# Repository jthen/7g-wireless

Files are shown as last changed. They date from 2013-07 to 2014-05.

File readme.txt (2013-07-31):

I've added a few things since my last update.

The first is the ability to "play" a text string as keystrokes on the receiver. So, the keyboards sends the string "this is a message" to the receiver which is then translated into keystrokes. These keystrokes are then sent to the PC as if the user typed "this is a message".

I used this to build a menu system which at the moment is used to set the brightness of the LEDs and the output power of the transmitter. Pressing Func+Esc enters the menu and this is what it currently looks:

[code]
7G wireless
firmware build Jul 30 2013  13:38:18
battery voltage=2.83V
keyboard's been on for 0days 21hour 39min 10sec

what do you want to do?
F1 - change transmitter output power (current 0dBm)
F2 - change LED brightness (current 1)
Esc - exit menu
[/code]
Pressing F1 or F2 then opens a sub-menu which allows changing these values.

The menu shows the current battery voltage. This needs a little tweaking to be more accurate, but it serves it's purpose at the moment. In the next PCB revision, I want to improve the circuit which measures the voltage. I have to dig into the AVR datasheets and look for some examples.

The firmware also has a clock (watch) which starts when the keyboard receives power. That's the "keyboard's been on for..." part of the menu. This clock is used in the sleep system (see below), but can be used as a real clock too.

There is also a LED "driver" thing which allows sequences to be replayed. So, for instance, I can play an LED sequence where 1 LED is on for a while, then 2, then all three. The driver also allows gradual transitions from bright do dim and back, but this still needs some testing, I think there are bugs in it. This can be used for all sorts of indicators.

The bad news: transmitter range sucks! On highest transmitter output power (0dBm) I get a range of 6-8 meters, and on the lowest I get 1-2 meters tops. I've used these modules for other projects, and I've confirmed a range of at least 60 meters. The chip should also be able to send a signal through at least one wall, which is not the case now. This, of course, means there is something wrong. I don't know what causes these, but I'm guessing either the keyboard PCB or my controller PCB are somehow shielding the transmitter. Tests are needed...

I don't do any frequency hopping. The channel is hard-coded at the moment. The transmitter will to re-send the package for for a number of times, or until it gets an acknowledge from the dongle.

The controller does not have any reverse voltage protection. So, reversing the batteries will probably fry the entire circuit. I will have to add this in the next controller revision.

The firmware doesn't do any encryption of the data it sends. This means that it's not too hard to build a circuit that can "listen" and log keystrokes. This can be fixed, of course, but it's not very high on my priority list. I'm not very paranoid...

The firmware puts the keyboard into sleep for a variable duration of time which depends on the time since the last change of the state of the keys. The idea is that while the user is typing, this sleep time will stay relatively short (say, 4ms) and if the user is not typing this interval will gradually increase to a max value (at the moment 71ms). Then, as soon as the user starts typing again, the sleep duration will jump back to the minimal value. Currently the implementaion of this is very crude, and needs more work. I plan to make this configurable so that the user can select if he wants to save power with longer sleeps, or have a more responsive keyboard and drain the batteries quicker. I also thought about making a "deep sleep" mode which puts the keyboard in a state where it will sleep for longer durations (say, 500ms) between matrix scans and wait for a specific key combination to get out of this deep sleep. The idea here is that you want to put the keyboard in deep sleep if you want to transport it, or if you want to lock it. The keyboard could also go into deep sleep if no keys have been pressed for a long time (30 minutes or so) to preserve power.

Because of this sleep system I decided I will not do any debouncing. What's the point of debouncing if I'm already scanning the keyboard matrix every 4ms or longer? Any comments on this?

The source code and the Eagle CAD schematics of the controller PCB are on:

https://code.google.com/p/7g-wireless/

So, that's it for now.

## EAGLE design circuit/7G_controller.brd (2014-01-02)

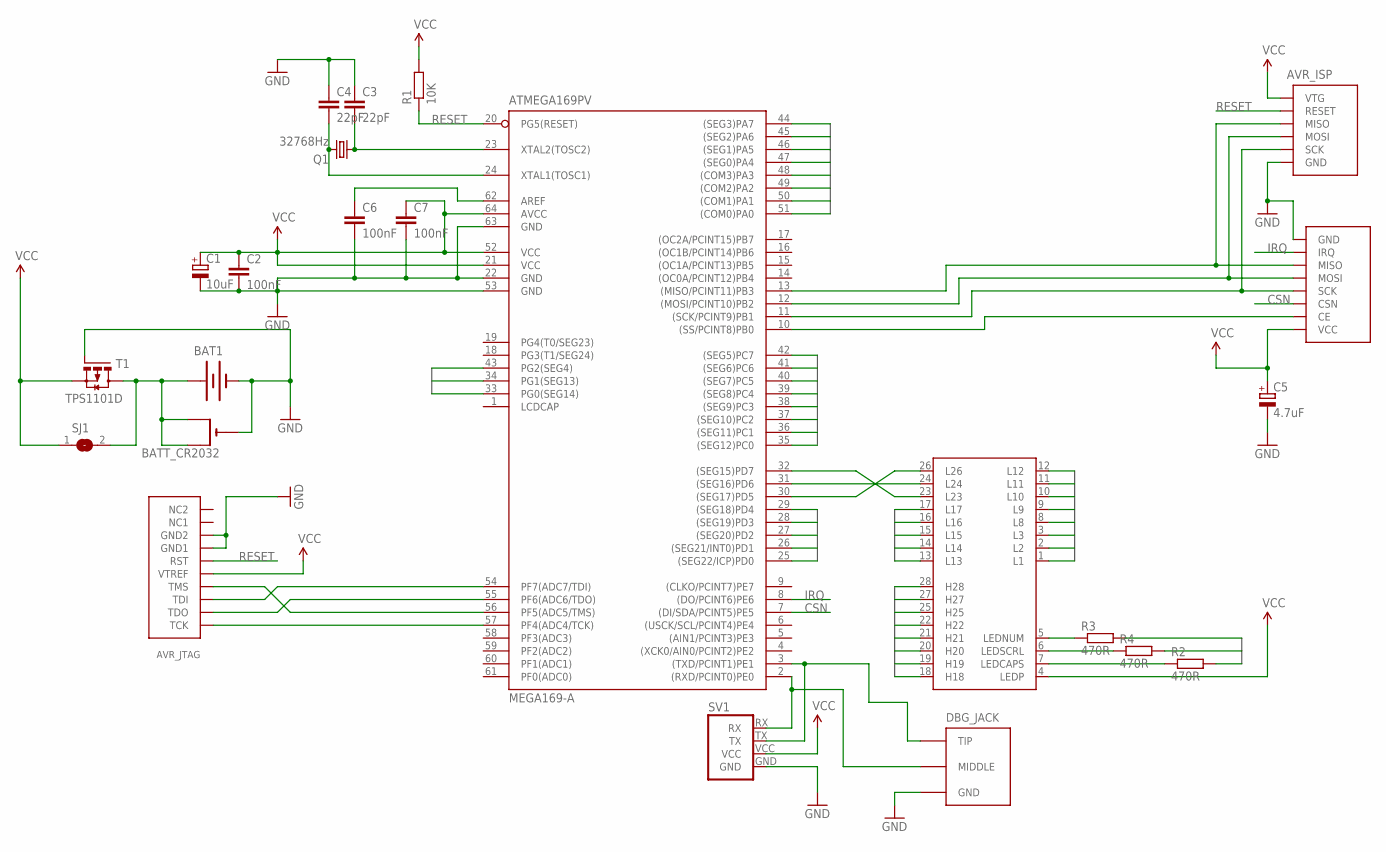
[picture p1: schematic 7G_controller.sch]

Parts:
ATMEGA169PV: MEGA169-A; TQFP64
AVR_ISP: AVR-ISP-6SMALL_FP; AVR-ISP-6-SMALL-FP
AVR_JTAG: AVR-JTAG
BAT1: BATTERYPLAIN; BATTERY
BATT_CR2032: CR2032SMT; CR2032-SMD
C1: 10uF; SMC_B
C2, C6, C7: 100nF; C0805
C3, C4: 22pF; C0805
C5: 4.7uF; SMC_B
DBG_JACK: JACK_FEMALE_3.5MMCHEAP; JACK_CHEAP
MTRX_CONN: SS7G_CONNSMD; SS7G_CONN_SMD
NRF24L01: NRF24L01_MOD_NINE_EAGLESGENERIC; NRF24L01_MOD_GENERIC
Q1: 32768Hz; NSK_QUARTZ_CLOCK
R1: 10K; R0805
R2, R3, R4: 470R; R0805
SJ1: SJ
SV1: UART_PORT
T1: TPS1101D; SO8

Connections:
AREF: ATMEGA169PV.62 (AREF), C6.1
CAPS: ATMEGA169PV.43 (PG2(SEG4)), R2.2
CE: ATMEGA169PV.10 ((SS/PCINT8)PB0), NRF24L01.CE
CSN: ATMEGA169PV.7 ((DI/SDA/PCINT5)PE5), NRF24L01.CSN
GND: ATMEGA169PV.22 (GND), ATMEGA169PV.53 (GND), ATMEGA169PV.63 (GND), AVR_ISP.GND, AVR_JTAG.P$2 (GND1), AVR_JTAG.P$10 (GND2), BAT1.-, BATT_CR2032.-, C1.-, C2.2, C3.1, C4.1, C5.-, C6.2, C7.2, DBG_JACK.1 (GND), NRF24L01.GND, SV1.GND, T1.4 (G)
H18: ATMEGA169PV.42 ((SEG5)PC7), MTRX_CONN.18 (H18)
H19: ATMEGA169PV.41 ((SEG6)PC6), MTRX_CONN.19 (H19)
H20: ATMEGA169PV.40 ((SEG7)PC5), MTRX_CONN.20 (H20)
H21: ATMEGA169PV.38 ((SEG9)PC3), MTRX_CONN.21 (H21)
H22: ATMEGA169PV.36 ((SEG11)PC1), MTRX_CONN.22 (H22)
H25: ATMEGA169PV.35 ((SEG12)PC0), MTRX_CONN.25 (H25)
H27: ATMEGA169PV.37 ((SEG10)PC2), MTRX_CONN.27 (H27)
H28: ATMEGA169PV.39 ((SEG8)PC4), MTRX_CONN.28 (H28)
IRQ: ATMEGA169PV.8 ((DO/PCINT6)PE6), NRF24L01.IRQ
L1: ATMEGA169PV.50 ((COM1)PA1), MTRX_CONN.1 (L1)
L2: ATMEGA169PV.48 ((COM3)PA3), MTRX_CONN.2 (L2)
L3: ATMEGA169PV.46 ((SEG1)PA5), MTRX_CONN.3 (L3)
L8: ATMEGA169PV.45 ((SEG2)PA6), MTRX_CONN.8 (L8)
L9: ATMEGA169PV.44 ((SEG3)PA7), MTRX_CONN.9 (L9)
L10: ATMEGA169PV.25 ((SEG22/ICP)PD0), MTRX_CONN.10 (L10)
L11: ATMEGA169PV.26 ((SEG21/INT0)PD1), MTRX_CONN.11 (L11)
L12: ATMEGA169PV.27 ((SEG20)PD2), MTRX_CONN.12 (L12)
L13: ATMEGA169PV.28 ((SEG19)PD3), MTRX_CONN.13 (L13)
L14: ATMEGA169PV.29 ((SEG18)PD4), MTRX_CONN.14 (L14)
L15: ATMEGA169PV.51 ((COM0)PA0), MTRX_CONN.15 (L15)
L16: ATMEGA169PV.49 ((COM2)PA2), MTRX_CONN.16 (L16)
L17: ATMEGA169PV.47 ((SEG0)PA4), MTRX_CONN.17 (L17)
LEDCAPS: MTRX_CONN.7 (LEDCAPS), R2.1
LEDNUM: MTRX_CONN.6 (LEDSCRL), R4.1
LEDSCRL: MTRX_CONN.5 (LEDNUM), R3.1
MISO: ATMEGA169PV.13 ((MISO/PCINT11)PB3), AVR_ISP.MISO, NRF24L01.MISO
MOSI: ATMEGA169PV.12 ((MOSI/PCINT10)PB2), AVR_ISP.MOSI, NRF24L01.MOSI
unnamed: ATMEGA169PV.32 ((SEG15)PD7), MTRX_CONN.23 (L23)
unnamed: BAT1.+, BATT_CR2032.+$1 (+), BATT_CR2032.+$2 (+1), SJ1.2, T1.5 (D), T1.6 (D), T1.7 (D), T1.8 (D)
unnamed: ATMEGA169PV.23 (XTAL2(TOSC2)), C3.2, Q1.1
unnamed: ATMEGA169PV.24 (XTAL1(TOSC1)), C4.2, Q1.4 (2)
unnamed: ATMEGA169PV.30 ((SEG17)PD5), MTRX_CONN.26 (L26)
unnamed: ATMEGA169PV.31 ((SEG16)PD6), MTRX_CONN.24 (L24)
unnamed: ATMEGA169PV.2 ((RXD/PCINT0)PE0), DBG_JACK.4 (MIDDLE), SV1.RX
unnamed: ATMEGA169PV.3 ((TXD/PCINT1)PE1), DBG_JACK.2 (TIP), DBG_JACK.3 (TIP), SV1.TX
NUML: ATMEGA169PV.33 (PG0(SEG14)), R3.2
RESET: ATMEGA169PV.20 (PG5(RESET)), AVR_ISP.RESET, AVR_JTAG.P$6 (RST), R1.1
SCK: ATMEGA169PV.11 ((SCK/PCINT9)PB1), AVR_ISP.SCK, NRF24L01.SCK
SCRL: ATMEGA169PV.34 (PG1(SEG13)), R4.2
TCK: ATMEGA169PV.57 (PF4(ADC4/TCK)), AVR_JTAG.P$1 (TCK)
TDI: ATMEGA169PV.54 (PF7(ADC7/TDI)), AVR_JTAG.P$9 (TDI)
TDO: ATMEGA169PV.55 (PF6(ADC6/TDO)), AVR_JTAG.P$3 (TDO)
TMS: ATMEGA169PV.56 (PF5(ADC5/TMS)), AVR_JTAG.P$5 (TMS)
VCC: ATMEGA169PV.21 (VCC), ATMEGA169PV.52 (VCC), ATMEGA169PV.64 (AVCC), AVR_ISP.VCC (VTG), AVR_JTAG.P$4 (VTREF), C1.+, C2.1, C5.+, C7.1, MTRX_CONN.4 (LEDP), NRF24L01.+3.3V (VCC), R1.2, SJ1.1, SV1.VCC, T1.1 (S), T1.2 (S), T1.3 (S)

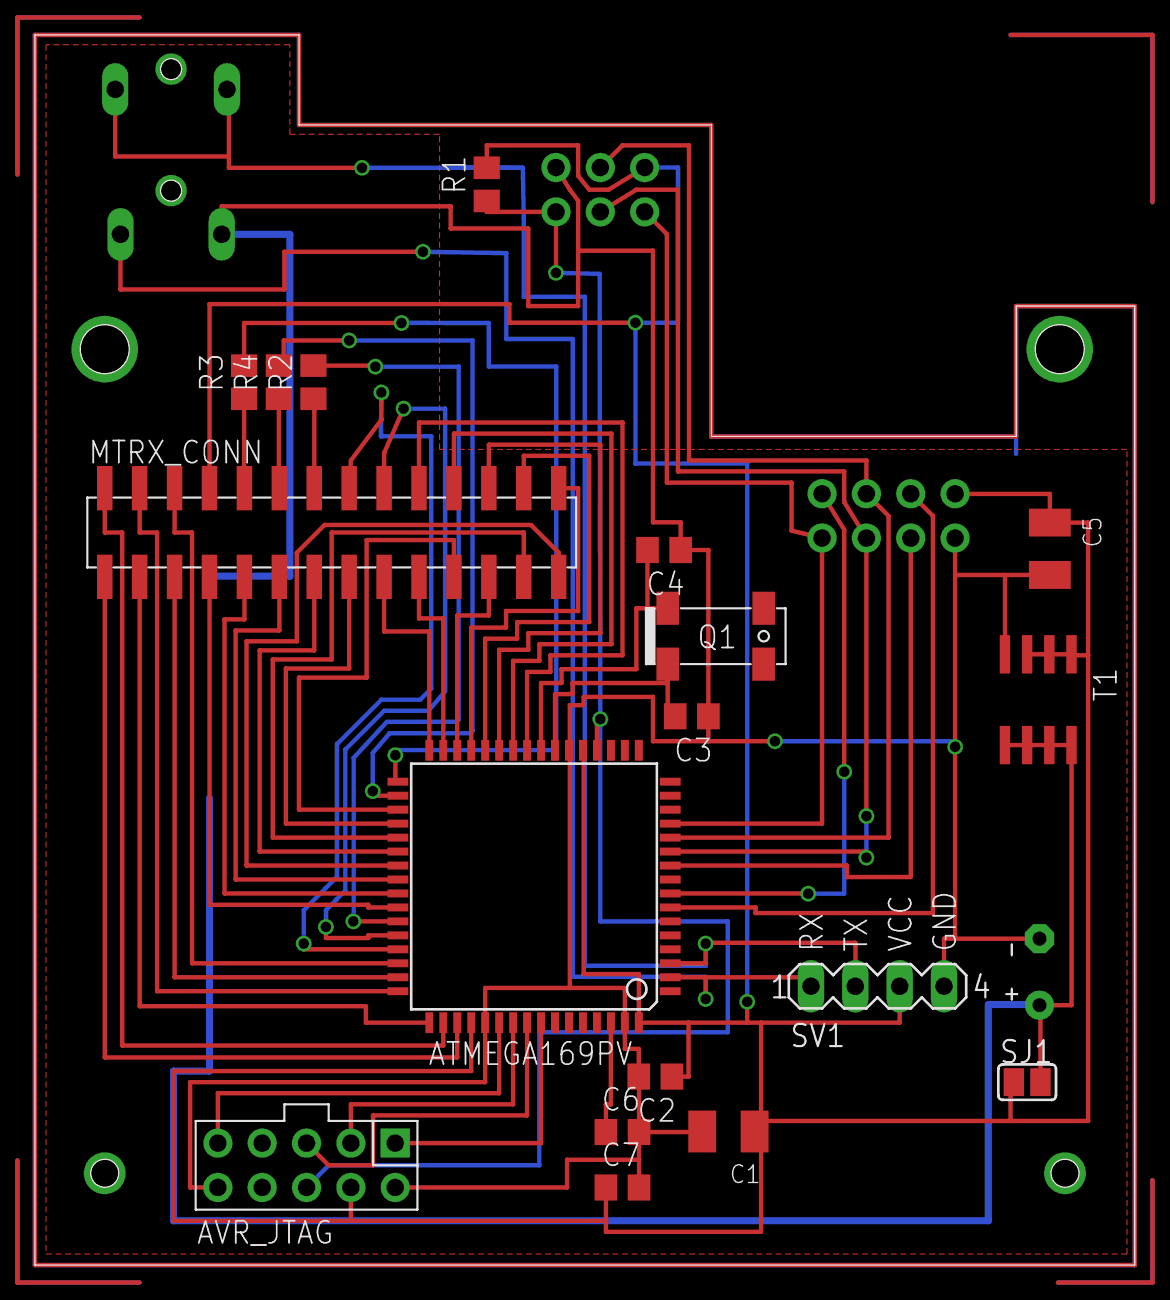
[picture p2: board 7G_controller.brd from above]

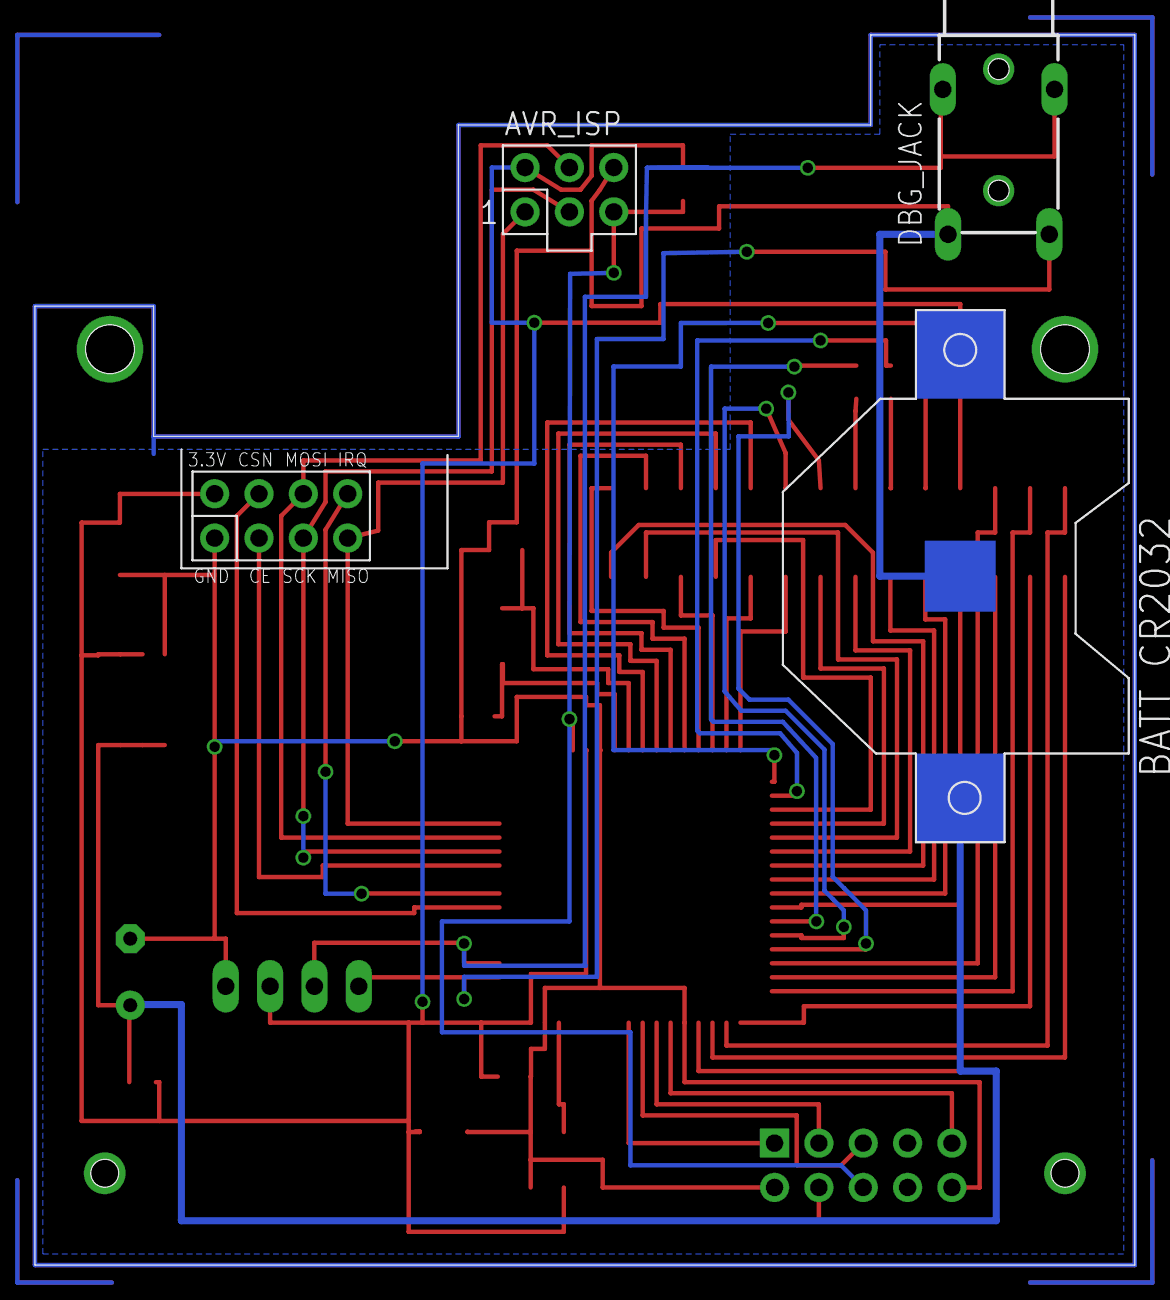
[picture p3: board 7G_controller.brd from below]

Board: 2 copper layers, 63.0 x 70.5 mm, 23 parts (4 on the bottom side), 49 nets.

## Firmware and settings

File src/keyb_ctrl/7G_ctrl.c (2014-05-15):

#include <stdint.h>
#include <stdbool.h>
#include <stdio.h>
#include <stdlib.h>
#include <string.h>

#include <avr/io.h>
#include <avr/pgmspace.h>
#include <avr/power.h>
#include <avr/interrupt.h>
#include <util/delay.h>

#include "hw_setup.h"
#include "avrdbg.h"
#include "avrutils.h"
#include "matrix.h"
#include "led.h"
#include "nRF24L.h"
#include "rf_protocol.h"
#include "rf_ctrl.h"
#include "keycode.h"
#include "sleeping.h"
#include "ctrl_settings.h"

// returns false if we should enter the menu, true if we should lock the keyboard
bool process_normal(void)
{
	bool waiting_for_all_keys_up = false;
	bool are_all_keys_up;
	bool ret_val = false;

	do {
		wait_for_matrix_change();

		// make a key state report
		rf_msg_key_state_report_t report;
		report.msg_type = MT_KEY_STATE;
		report.modifiers = 0;
		report.consumer = 0;

		uint8_t num_keys = 0;

		are_all_keys_up = true;
		
		if (is_pressed_keycode(KC_FN0))
		{
			are_all_keys_up = false;
			
			// set the bits of the consumer byte (media keys)
			if (is_pressed_keycode(KC_F1))		report.consumer |= _BV(FN_MUTE_BIT);
			if (is_pressed_keycode(KC_F2))		report.consumer |= _BV(FN_VOL_DOWN_BIT);
			if (is_pressed_keycode(KC_F3))		report.consumer |= _BV(FN_VOL_UP_BIT);
			if (is_pressed_keycode(KC_F4))		report.consumer |= _BV(FN_PLAY_PAUSE_BIT);
			if (is_pressed_keycode(KC_F5))		report.consumer |= _BV(FN_PREV_TRACK_BIT);
			if (is_pressed_keycode(KC_F6))		report.consumer |= _BV(FN_NEXT_TRACK_BIT);

			// if only Func and Esc are pressed
			if (get_num_keys_pressed() == 2)
			{
				if (is_pressed_keycode(KC_ESC))
				{
					waiting_for_all_keys_up = true;
				} else if (is_pressed_keycode(KC_L)) {
					waiting_for_all_keys_up = true;
					ret_val = true;
				} else if (is_pressed_keycode(KC_KP_MINUS)) {

					uint8_t curr_power = get_nrf_output_power();

					if (curr_power == vRF_PWR_0DBM)
						set_nrf_output_power(vRF_PWR_M6DBM);
					else if (curr_power == vRF_PWR_M6DBM)
						set_nrf_output_power(vRF_PWR_M12DBM);
					else if (curr_power == vRF_PWR_M12DBM)
						set_nrf_output_power(vRF_PWR_M18DBM);

				} else if (is_pressed_keycode(KC_KP_PLUS)) {

					uint8_t curr_power = get_nrf_output_power();

					if (curr_power == vRF_PWR_M18DBM)
						set_nrf_output_power(vRF_PWR_M12DBM);
					else if (curr_power == vRF_PWR_M12DBM)
						set_nrf_output_power(vRF_PWR_M6DBM);
					else if (curr_power == vRF_PWR_M6DBM)
						set_nrf_output_power(vRF_PWR_0DBM);
				}
			}

		} else {

			uint8_t row, col;
			for (row = 0; row < NUM_ROWS; ++row)
			{
				for (col = 0; col < NUM_COLS; ++col)
				{
					if (is_pressed_matrix(row, col))
					{
						are_all_keys_up = false;
						
						uint8_t keycode = get_keycode(row, col);
						
						if (IS_MOD(keycode))
							report.modifiers |= _BV(keycode - KC_LCTRL);
						else if (num_keys < MAX_KEYS)
							report.keys[num_keys++] = keycode;
					}
				}
			}
		}

		// send the report and wait for ACK
		if (!rf_ctrl_send_message(&report, num_keys + 3))
			return true;

		// flush the ACK payloads
		rf_ctrl_process_ack_payloads(NULL, NULL);
		
	} while (!waiting_for_all_keys_up  ||  are_all_keys_up);
	
	return ret_val;
}

bool send_text(const char* msg, bool is_flash, bool wait_for_finish)
{
#ifdef DBGPRINT
	// This needs an explanation: I am using the AVR Dragon to flash the keyboard firmware
	// and it looks like the dragon has a strong pullup on the MISO line. This pullup is
	// stronger than the nRF24L01+ MISO output driver, so if the programming ISP cable is plugged in
	// it keeps MISO high all the time, and I can't read anything from the nRF24L01+ and the send_text()
	// function will never return.
	//
	// So, instead of plugging the ISP cable in and out all the time while testing firmware updates,
	// we just output the text to UART and return
	if (is_flash)
		dprint_P(msg);
	else
		dprint(msg);
	_delay_ms(1);
	return true;
#endif

	// this message id is used to avoid presenting the same package to the dongle in case dongle
	// received the message, but the keyboard did not receive the ACK
	static uint8_t msg_id = 1;
	
	rf_msg_text_t txt_msg;
	txt_msg.msg_type = MT_TEXT;

	// send the message in chunks of MAX_TEXT_LEN
	uint16_t msglen = is_flash ? strlen_P(msg) : strlen(msg);
	uint8_t chunklen, msg_bytes_free;
	while (msglen)
	{
		// flush the ACK payload
		rf_ctrl_process_ack_payloads(&msg_bytes_free, NULL);
	
		// copy a chunk of the message
		chunklen = msglen > MAX_TEXT_LEN ? MAX_TEXT_LEN : msglen;
		if (is_flash)
			memcpy_P(txt_msg.text, msg, chunklen);
		else
			memcpy(txt_msg.text, msg, chunklen);

		msglen -= chunklen;
		msg += chunklen;

		// query the free space of the buffer on the dongle to see if
		// it is large enough to store the next chunk

		for (;;)
		{
			// send an empty text message; this causes the dongle to respond with ACK payload
			// that contains the number of bytes available in the dongle's text buffer
			if (!rf_ctrl_send_message(&txt_msg, 2))		// 1 byte for the message type ID, 1 for the msg_id
				return false;
			
			rf_ctrl_process_ack_payloads(&msg_bytes_free, NULL);
			
			// enough space in the dongle buffer?
			if (msg_bytes_free > chunklen + 1)
				break;
				
			sleep_ticks(40);		// doze off a little; roughly 10ms
		}
		
		// set the message id and send it on it's way
		msg_id = msg_id == 0xff ? 1 : msg_id + 1;
		txt_msg.msg_id = msg_id;
		if (!rf_ctrl_send_message(&txt_msg, chunklen + 2))
			return false;
	}

	// flush the ACK payload(s)
	rf_ctrl_process_ack_payloads(NULL, NULL);

	// wait for the buffer on the dongle to become empty
	// this will ensure that all the keystrokes are sent to the host and that subsequent
	// keystrokes we're sending won't mess up the text we want output at the host
	if (wait_for_finish)
	{
		uint8_t msg_bytes_capacity = 0;
		do {
			if (!rf_ctrl_send_message(&txt_msg, 2))
				return false;

			rf_ctrl_process_ack_payloads(&msg_bytes_free, &msg_bytes_capacity);
		} while (msg_bytes_free == 0  ||  msg_bytes_free != msg_bytes_capacity);
	}
	
	return true;
}

// defining this makes the ADC use the two least significant bits, but adds 24 bytes to the binary
#define PREC_BATT_VOLTAGE

// returns the battery voltage in 10mV units
// for instance: get_battery_voltage() returning 278 equals a voltage of 2.78V
uint16_t get_battery_voltage(void)
{
	power_adc_enable();
	
	ADMUX = _B0(REFS1) | _B1(REFS0)	// AVCC with external capacitor at AREF pin
#ifndef PREC_BATT_VOLTAGE	
			| _BV(ADLAR)			// left adjust ADC - drops the two LSBs
#endif
			| 0b11110;				// measure 1.1v internal reference

	ADCSRA = _BV(ADEN)					// enable ADC
			| _BV(ADPS2) | _BV(ADPS1) | _BV(ADPS0)	// prescaler 128
			| _BV(ADSC);				// start conversion
	
	// wait for the conversion to finish
	loop_until_bit_is_set(ADCSRA, ADIF);

	// remember the result
#ifdef PREC_BATT_VOLTAGE
	uint16_t adc_result = ADC;
#else	
	uint8_t adc_result = ADCH;
#endif
	
	// clear the ADIF bit by writing one
	SetBit(ADCSRA, ADIF);
	
	ADCSRA = 0;				// disable ADC
	
	power_adc_disable();	// ADC power off
	
#ifdef PREC_BATT_VOLTAGE
	return 112640 / adc_result;
#else
	return 28050 / adc_result;
#endif
}

// makes a battery voltage string in the 2.34V format
// the buff buffer has to be at least 6 bytes long
void get_battery_voltage_str(char* buff)
{
	uint16_t voltage = get_battery_voltage();
	buff[0] = '0' + voltage / 100;
	buff[1] = '.';
	buff[2] = '0' + (voltage / 10) % 10;
	buff[3] = '0' + voltage % 10;
	buff[4] = 'V';
	buff[5] = '\0';
}

// returns the keycode of the first key pressed and relased
uint8_t get_key_input(void)
{
	uint8_t keycode_pressed = KC_NO;
	
	wait_for_all_keys_up();
	wait_for_key_down();

	// scan for the key pressed
	uint8_t row, col;
	for (row = 0; row < NUM_ROWS; ++row)
	{
		for (col = 0; col < NUM_COLS; ++col)
		{
			if (is_pressed_matrix(row, col))
				keycode_pressed = get_keycode(row, col);
		}
	}
	
	wait_for_all_keys_up();
	
	return keycode_pressed;
}

bool process_menu(void)
{
	start_led_sequence(led_seq_menu_begin);
	
	// print the main menu
	uint8_t keycode;
	char* pEnd;
	const uint8_t BUFF_SIZE = 64;
	char string_buff[BUFF_SIZE];
	for (;;)
	{
		// welcome & version
		if (!send_text(PSTR("\x01"	// translates to Ctrl-A on the dongle
							"7G wireless\n"
							"firmware build " __DATE__ "  " __TIME__ "\n"
							"battery voltage: "), true, false))
			return true;
			
		get_battery_voltage_str(string_buff);
		if (!send_text(string_buff, false, false))		return true;

		// RF stats
		if (!send_text(PSTR("\nRF packet stats (total/retransmit/lost): "), true, false))		return true;
		
		ultoa(rf_packets_total, string_buff, 10);
		pEnd = strchr(string_buff, '\0');
		*pEnd++ = '/';
		
		ultoa(arc_total, pEnd, 10);
		pEnd = strchr(string_buff, '\0');
		*pEnd++ = '/';

		ultoa(plos_total, pEnd, 10);
		if (!send_text(string_buff, false, false))		return true;
		
		// output the time since reset
		uint16_t days;
		uint8_t hours, minutes, seconds;
		get_time(&days, &hours, &minutes, &seconds);
		if (!send_text(PSTR("\nkeyboard's been on for "), true, false))		return true;
		
		string_buff[0] = '\0';
		if (days > 0)
		{
			itoa(days, string_buff, 10);
			strcat_P(string_buff, PSTR(" days "));
		}

		if (hours > 0  ||  days > 0)
		{
			itoa(hours, strchr(string_buff, 0), 10);
			pEnd = strlcat_P(string_buff, PSTR(" hours "), BUFF_SIZE) + string_buff;
		} else {
			pEnd = strchr(string_buff, 0);
		}

		itoa(minutes, pEnd, 10);
		pEnd = strlcat_P(string_buff, PSTR(" minutes "), BUFF_SIZE) + string_buff;

		itoa(seconds, pEnd, 10);
		strcat_P(string_buff, PSTR(" seconds\n"));
		
		if (!send_text(string_buff, false, false))		return true;
		
		// menu
		if (!send_text(PSTR("\n\nwhat do you want to do?\n"
							"F1 - change transmitter output power (current "), true, false))		return true;
		switch (get_nrf_output_power())
		{
		case vRF_PWR_M18DBM:	send_text(PSTR("-18"), true, false); 	break;
		case vRF_PWR_M12DBM:	send_text(PSTR("-12"), true, false); 	break;
		case vRF_PWR_M6DBM:		send_text(PSTR("-6"), true, false); 	break;
		case vRF_PWR_0DBM:		send_text(PSTR("0"), true, false); 		break;
		}
		
		if (!send_text(PSTR("dBm)\nF2 - change LED brightness (current "), true, false))		return true;
		
		uint8_t fcnt;
		for (fcnt = 0; fcnt < sizeof led_brightness_lookup; ++fcnt)
		{
			if (led_brightness_lookup[fcnt] == get_led_brightness())
			{
				string_buff[0] = 'F';
				itoa(fcnt + 1, string_buff + 1, 10);
				break;
			}
		}
		
		// no match found in the loop?
		if (fcnt == sizeof led_brightness_lookup)
			itoa(get_led_brightness(), string_buff, 10);

		if (!send_text(string_buff, false, false))		return true;
		
		if (!send_text(PSTR(")\nF3 - lock keyboard (unlock with Func+Del+LCtrl)\n"
							"F4 - reset RF packet stats\n"
							"F5 - refresh this menu\n"
							"Esc - exit menu\n\n"), true, false))
			return true;

		do {
			keycode = get_key_input();
		} while (!(keycode >= KC_F1  &&  keycode <= KC_F5)  &&  keycode != KC_ESC);

		if (keycode == KC_F1)
		{
			if (!send_text(PSTR("select power:\nF1 0dBm\nF2 -6dBm\nF3 -12dBm\nF4 -18dBm\n"), true, false))
				return true;
			
			while (1)
			{
				keycode = get_key_input();
				if (keycode >= KC_F1  &&  keycode <= KC_F4)
				{
					if (keycode == KC_F1)	set_nrf_output_power(vRF_PWR_0DBM);
					if (keycode == KC_F2)	set_nrf_output_power(vRF_PWR_M6DBM);
					if (keycode == KC_F3)	set_nrf_output_power(vRF_PWR_M12DBM);
					if (keycode == KC_F4)	set_nrf_output_power(vRF_PWR_M18DBM);
					break;
				}
			}
		} else if (keycode == KC_F2) {
			if (!send_text(PSTR("press F1 (dim) to F12 (bright) for brightness, Esc to finish\n"), true, false))
				return true;
			
			do {
				keycode = get_key_input();
				if (keycode >= KC_F1  &&  keycode <= KC_F12)
				{
					set_led_brightness(led_brightness_lookup[keycode - KC_F1]);
					set_leds(7, 50);
				}
			} while (keycode != KC_ESC);
			
		} else if (keycode == KC_F3) {
			send_text(PSTR("Keyboard is now LOCKED!!!\nPress Func+Del+LCtrl to unlock\n\n"), true, false);
			return true;

		} else if (keycode == KC_F4) {

			// reset the counters to 0
			plos_total = arc_total = rf_packets_total = 0;
			
		} else if (keycode == KC_ESC) {

			start_led_sequence(led_seq_menu_end);
			send_text(PSTR("\nexiting menu, you can type now\n"), true, true);
			break;
		}
	}
	
	return false;
}

void process_lock(void)
{
	start_led_sequence(led_seq_lock);

	for (;;)
	{
		sleep_ticks(0xfe);	// long, about 62ms x 3 = 190ms
		sleep_ticks(0xfe);
		sleep_ticks(0xfe);

		if (matrix_scan()
				&&  get_num_keys_pressed() == 3
				&&  is_pressed_keycode(KC_FN0)
				&&  (is_pressed_keycode(KC_LCTRL)  ||  is_pressed_keycode(KC_RCTRL))
				&&  (is_pressed_keycode(KC_DEL)  ||  is_pressed_keycode(KC_KP_DOT)))
		{
			break;
		}
	}

	start_led_sequence(led_seq_lock);
}

void init_hw(void)
{
	// power down everything we don't need
	power_adc_disable();	// get_battery_voltage() turns this back on and off again
	power_lcd_disable();
	//power_spi_disable();	// maybe we should power this off when not in use?
	power_timer1_disable();
	power_usart0_disable();	// init_dbg() will power on the USART if called
	SetBit(ACSR, ACD);		// analog comparator off
	
	OSCCAL = 103;			// RC oscillator calibration done externally.
							// for now, just hard-code it to this value
	
	// default all pins to input with pullups
	DDRA = 0;	PORTA = 0xff;
	DDRB = 0;	PORTB = 0xff;
	DDRC = 0;	PORTC = 0xff;
	DDRD = 0;	PORTD = 0xff;
	DDRE = 0;	PORTE = 0xff;
	DDRF = 0;	PORTF = 0xff;
	DDRG = 0;	PORTG = 0xff;
	
	// PE0 and PE1 are used for timing and debugging
	// Note: these are the UART RX (PE0) and TX (PE1) pins
	
	//DDRE = _BV(0) | _BV(1);

	matrix_init();
	rf_ctrl_init();
	init_leds();
	init_sleep();
#ifdef DBGPRINT	
	init_dbg();
#endif
}

int main(void)
{
	init_hw();	// initialize the hardware

	sei();		// enable interrupts

	// 'play' a LED sequence while waiting for the 32KHz crystal to stabilize
	start_led_sequence(led_seq_boot);
	while (are_leds_on())
		;
	
	for (;;)
	{
		if (process_normal()  ||  process_menu())
			process_lock();
	}

	return 0;
}

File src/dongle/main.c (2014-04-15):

#include <stdbool.h>
#include <stdio.h>
#include <stdint.h>
#include <string.h>

#include "reg24lu1.h"

#include "keycode.h"
#include "text_message.h"
#include "reports.h"
#include "rf_protocol.h"
#include "rf_dngl.h"
#include "nrfutils.h"

#include "usb.h"
#include "usb_regs.h"

#include "nrfdbg.h"

__xdata void* memcpy_X(__xdata void* dest, __xdata const void* src, size_t count)
{
	__xdata char* dst8 = (__xdata char*)dest;
	__xdata const char* src8 = (__xdata const char*)src;

	while (count--)
		*dst8++ = *src8++;

	return dest;
}

void* memcpy_P(__xdata void* dest, __code const void* src, size_t count)
{
	char* dst8 = (char*)dest;
	char* src8 = (char*)src;

	while (count--)
		*dst8++ = *src8++;

	return dest;
}

#define RECV_BUFF_SIZE		32

void main()
{
	bool keyboard_report_ready = false;
	bool consumer_report_ready = false;

	uint8_t prev_keycode = KC_NO;
	
	__xdata uint8_t recv_buffer[RECV_BUFF_SIZE];
	__xdata uint8_t bytes_received;
	
	P0DIR = 0x00;	// all outputs
	P0ALT = 0x00;	// all GPIO default behavior
	
	LED_off();

	usbInit();
	//dbgInit();
	
	rf_dngl_init();

	reset_keyboard_report();
	
	for (;;)
	{
		usbPoll();	// handles USB interrupts
		//dbgPoll();	// send chars from the uart TX buffer
		
		// try to read the recv buffer
		bytes_received = rf_dngl_recv(recv_buffer, RECV_BUFF_SIZE);

		if (bytes_received)
		{
			// we have new data, so what is it?
			if (recv_buffer[0] == MT_KEY_STATE)
			{
				process_key_state_msg(recv_buffer, bytes_received);

				consumer_report_ready = true;
				keyboard_report_ready = true;
			} else if (recv_buffer[0] == MT_TEXT) {
				process_text_msg(recv_buffer, bytes_received);
			}
		}

		if (!keyboard_report_ready  &&  !msg_empty())
		{
			// get the next char from the stored text message
			uint8_t c = msg_peek();
			uint8_t new_keycode = get_keycode_for_char(c);

			reset_keyboard_report();

			// if the keycode is different than the previous
			// otherwise just send an empty report to simulate key went up
			if (new_keycode != prev_keycode  ||  new_keycode == KC_NO)
			{
				usb_keyboard_report.keys[0] = new_keycode;
				usb_keyboard_report.modifiers = get_modifiers_for_char(c);
				
				msg_pop();	// remove char from the buffer
			} else {
				new_keycode = KC_NO;
			}
			
			keyboard_report_ready = true;
			
			prev_keycode = new_keycode;		// remember for later
		}
		
		// send the report if the endpoint is not busy
		if ((in1cs & 0x02) == 0   &&   (keyboard_report_ready  ||  usbHasIdleElapsed()))
		{
			// copy the keyboard report into the endpoint buffer
			in1buf[0] = usb_keyboard_report.modifiers;
			in1buf[1] = 0;
			in1buf[2] = usb_keyboard_report.keys[0];
			in1buf[3] = usb_keyboard_report.keys[1];
			in1buf[4] = usb_keyboard_report.keys[2];
			in1buf[5] = usb_keyboard_report.keys[3];
			in1buf[6] = usb_keyboard_report.keys[4];
			in1buf[7] = usb_keyboard_report.keys[5];

			// send the data on it's way
			in1bc = 8;
			
			keyboard_report_ready = false;
		}

		// send the consumer report if the endpoint is not busy
		if ((in2cs & 0x02) == 0   &&   (consumer_report_ready  ||  usbHasIdleElapsed()))
		{
			in2buf[0] = usb_consumer_report;
			in2bc = 1;
		
			consumer_report_ready = false;
		}
	}
}

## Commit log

2013-08-27 fixed the LED sequence replay bugs
    [7G_ctrl.c, led.c]
2013-08-27 renamed avr_serial -> avrdbg
    [7G_controller.brd, 7G_controller.sch]
2013-12-29 CR2032 holder
    [7G_controller.brd, 7G_controller.sch]
2014-01-02 finished adding the CR2032 battery holder
    [7G_controller.brd, 7G_controller.sch]
2014-02-24 made the RF connect a little more reliable. fixed the lag menu of the menu system with full speed dongles
    [7G_ctrl.c, main.c]
2014-02-28 text messages should work reliably in noisy environments. added nRF UART debug output library
2014-03-01 added Func+KeypadPlus and Func+KeypadMinus for power increase and decrease
2014-03-30 switched to external mcu-lib

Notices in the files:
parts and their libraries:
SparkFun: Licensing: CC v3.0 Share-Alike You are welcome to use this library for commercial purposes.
